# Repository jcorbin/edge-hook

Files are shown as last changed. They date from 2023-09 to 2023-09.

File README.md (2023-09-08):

# [Parametric Edge Hook](https://than.gs/m/929226)

Reworked this "bathroom hoook" model: <https://www.myminifactory.com/object/3d-print-parametric-bathroom-hook-117600>

- for my application, I needed a shorter hook, but deeper to hold a hanging
  organizer flush with the edge of shelf, with minimal slop for vibration
  purposes
- cleaned up scad code a little
- rounded the back endcap
- centered model geometry fwiw

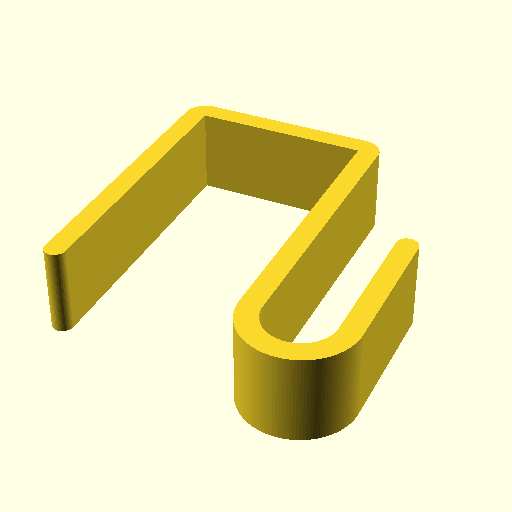
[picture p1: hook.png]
Example Model Image


# Suggested Slicer Settings

I used a 0.4mm nozzle, and sliced them to be "all walls":
- 3 walls
- 0% (no) infill
- 0 top/bottom layers

Here's what a pair of them looked like in my slicer:
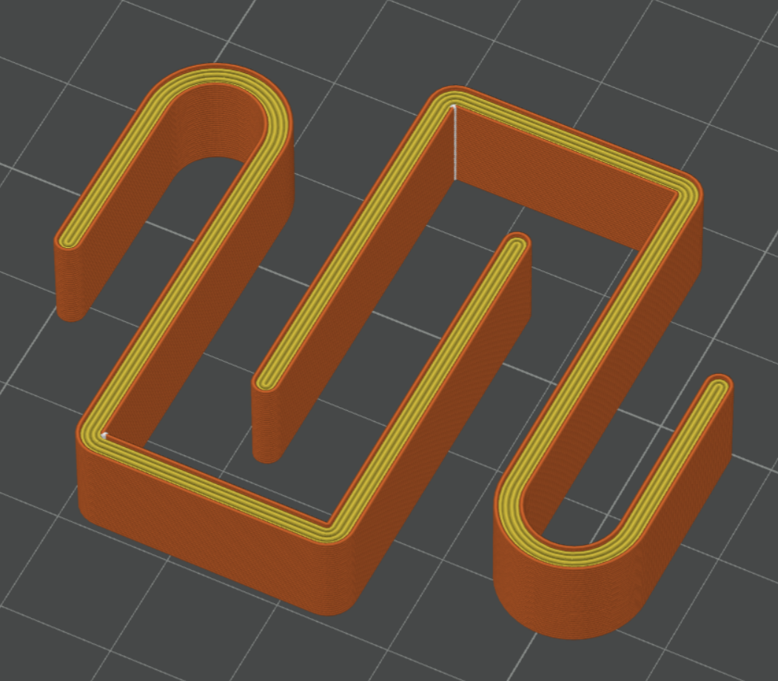
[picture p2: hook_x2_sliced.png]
Example Slicer Preview


[BY-NC-SA](https://creativecommons.org/licenses/by-nc-sa/4.0/)

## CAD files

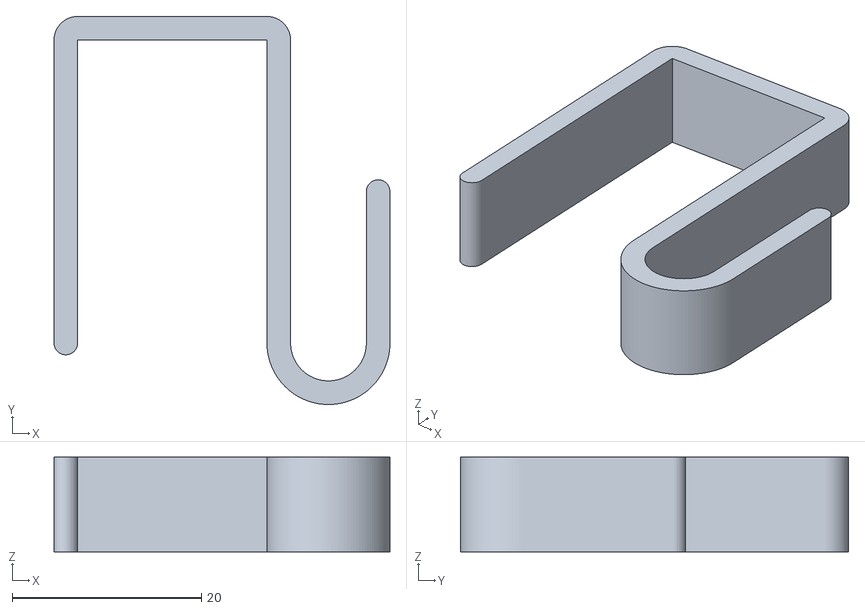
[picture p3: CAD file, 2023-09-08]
hook.stl
35.5 x 41.0 x 10.0

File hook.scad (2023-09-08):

// Simple hook to hang over partition or door.
// This design is parametric:
// turn off View->Hide Customizer to get an editor for these variables.
// All dimensions are in mm.
// Note that parameters are not sanity-checked.


// width of entire strip
width = 10;

// thickness of partition
depth = 20;

// thickness of entire strip
thickness = 2.5;

// how far clip descends behind partition
back_drop = 32;

// how far it drops in front of partition
front_drop = 36 - 4;

// inside radius of the hook part
hook_radius = 4;

// how far straight part of hook rises above curved part
hook_rise = 16;

// geometry resolution settings
$fa = 3;
$fs = 0.2;

module profile() {
  // the back drop
  translate([-hook_radius-depth-2*thickness, front_drop-back_drop])
    square([thickness, back_drop]);

  // round end of the back drop
  translate([-hook_radius-depth-3*thickness/2, front_drop-back_drop])
    circle(r=thickness/2);

  // fillet
  translate([-depth-hook_radius-thickness, front_drop])
  rotate(90)
    intersection() {
      circle(r=thickness);
      square(thickness);
    }

  // the top bit
  translate([-hook_radius-thickness-depth, front_drop])
    square([depth, thickness]);

  // fillet
  translate([-hook_radius-thickness, front_drop])
    intersection() {
     circle(r=thickness);
     square(thickness);
    }

  // the front drop
  translate([-hook_radius-thickness, 0])
    square([thickness, front_drop]);

  // the hook
  intersection() {
    translate([-hook_radius-thickness, -2*(hook_radius+thickness)])
      square(2*(hook_radius+thickness));
    difference() {
      circle(r=hook_radius+thickness);
      circle(r=hook_radius);
    }
  }

  // the hook riser
  translate([hook_radius, 0])
    square([thickness, hook_rise]);

  // round end of the hook
  translate([hook_radius+thickness/2, hook_rise])
    circle(r=thickness/2);
}

translate([
  (depth + thickness)/2,
  (hook_radius - front_drop)/2,
  -width/2,
])
linear_extrude(width)
  profile();

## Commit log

2023-09-08 Import from upstream
    <https://www.myminifactory.com/object/3d-print-parametric-bathroom-hook-117600>
    [hook.scad, hook.stl]
2023-09-08 Cleanup whitespace
    [hook.scad]
2023-09-08 Rework geometry resolution settings
    [hook.scad]
2023-09-08 Factor out profile module
    [hook.scad]
2023-09-08 Round the other endcap
    [hook.scad]
2023-09-08 Add makefile, remake stl
    [hook.stl]
2023-09-08 Center model geometry around origin
    [hook.scad]
2023-09-08 Change parameters for my application
    [hook.scad]
2023-09-08 Updates for publishing
    - add readme with images
    - add license
    - update makefile to maintain image
    [hook.stl]
